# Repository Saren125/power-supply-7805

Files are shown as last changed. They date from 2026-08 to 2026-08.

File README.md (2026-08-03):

# power-supply-7805
## Особенности реализации (Топология платы)
* Среда проектирования: **Altium Designer**
* Количество слоев: **1 слой (Односторонняя печатная плата)**. Проект разработан с учетом минимизации стоимости серийного производства.
* **Тепловой менеджмент (Thermal Design):** Отвод тепла от микросхемы LM7805 реализован за счет создания максимально возможной площади медного полигона непосредственно на сигнальном слое вокруг вкладки (Tab) регулятора.
* **Трассировка:** Компоновка элементов выполнена оптимальным образом, что позволило полностью избежать пересечения проводников на одном слое и отказаться от использования проволочных перемычек (Jumpers).
* Фильтрующие керамические конденсаторы С1 и С3 (0.1 мкФ) размещены в максимальной физической близости к выводам питания микросхемы.

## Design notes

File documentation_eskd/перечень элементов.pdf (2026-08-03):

Изм. Лист | № докум. | Подп. | Дата
| Разраб. | | | Стабилизатор напряжения Перечень элементов | Лит. | Лист | Листов
Пров. | | | | | | | 1
Н.контр. Инв. № подл. Подп. и дата Взам. инв. № Инв. № дубл. Подп. и дата | Утв. Справ. № Перв. примен. | Конденсаторы
С1,C3 | Конденсатор керамический 0.1 МКФ 50В 10% 0603 GCM188R71H104KA57D Murata | 2
C2 | Конденсатор электролитический 10мкФ 50В 20% JRB1H100M02000500110000B JRB | 1

Микросхемы

DD1 | Стабилизатор напряжения TO-220 L7805CV Hottech | 1
| Резисторы
R1 | Резистор 1 кОм 0.1 Вт 0603 RC0603JR-071KL YAGEO | 1
| Приборы полупроводниковые
VD1 | Диод импульсный SMB ES2D On-Semiconductor | 1
VD2 | Диод Шоттки SMB SS220 YANGJIE | 1
VD3 | Светодиод красный 0603 GNL-0603EC G-nor Electronics | 1

Соединители

XT1,XT2 Вилка штыревая 2.54мм 1x2pin прямая PLS-2 (DS1021-1x2) Connfly electronic (Zhenqin) 2

Поз.
обозначение
Наименование | Кол. Примечание
Копировал | Формат A4

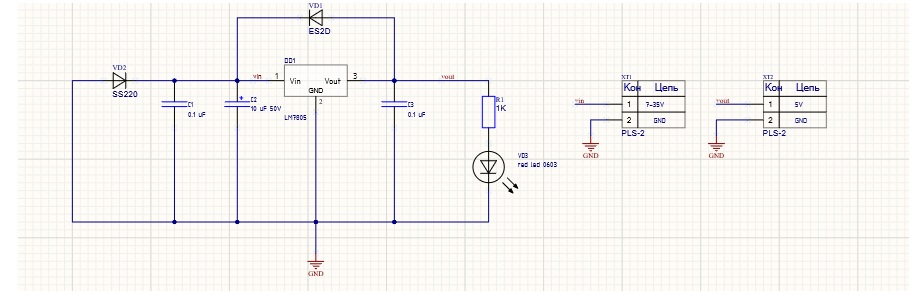
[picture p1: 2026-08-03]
screenshot.jpg

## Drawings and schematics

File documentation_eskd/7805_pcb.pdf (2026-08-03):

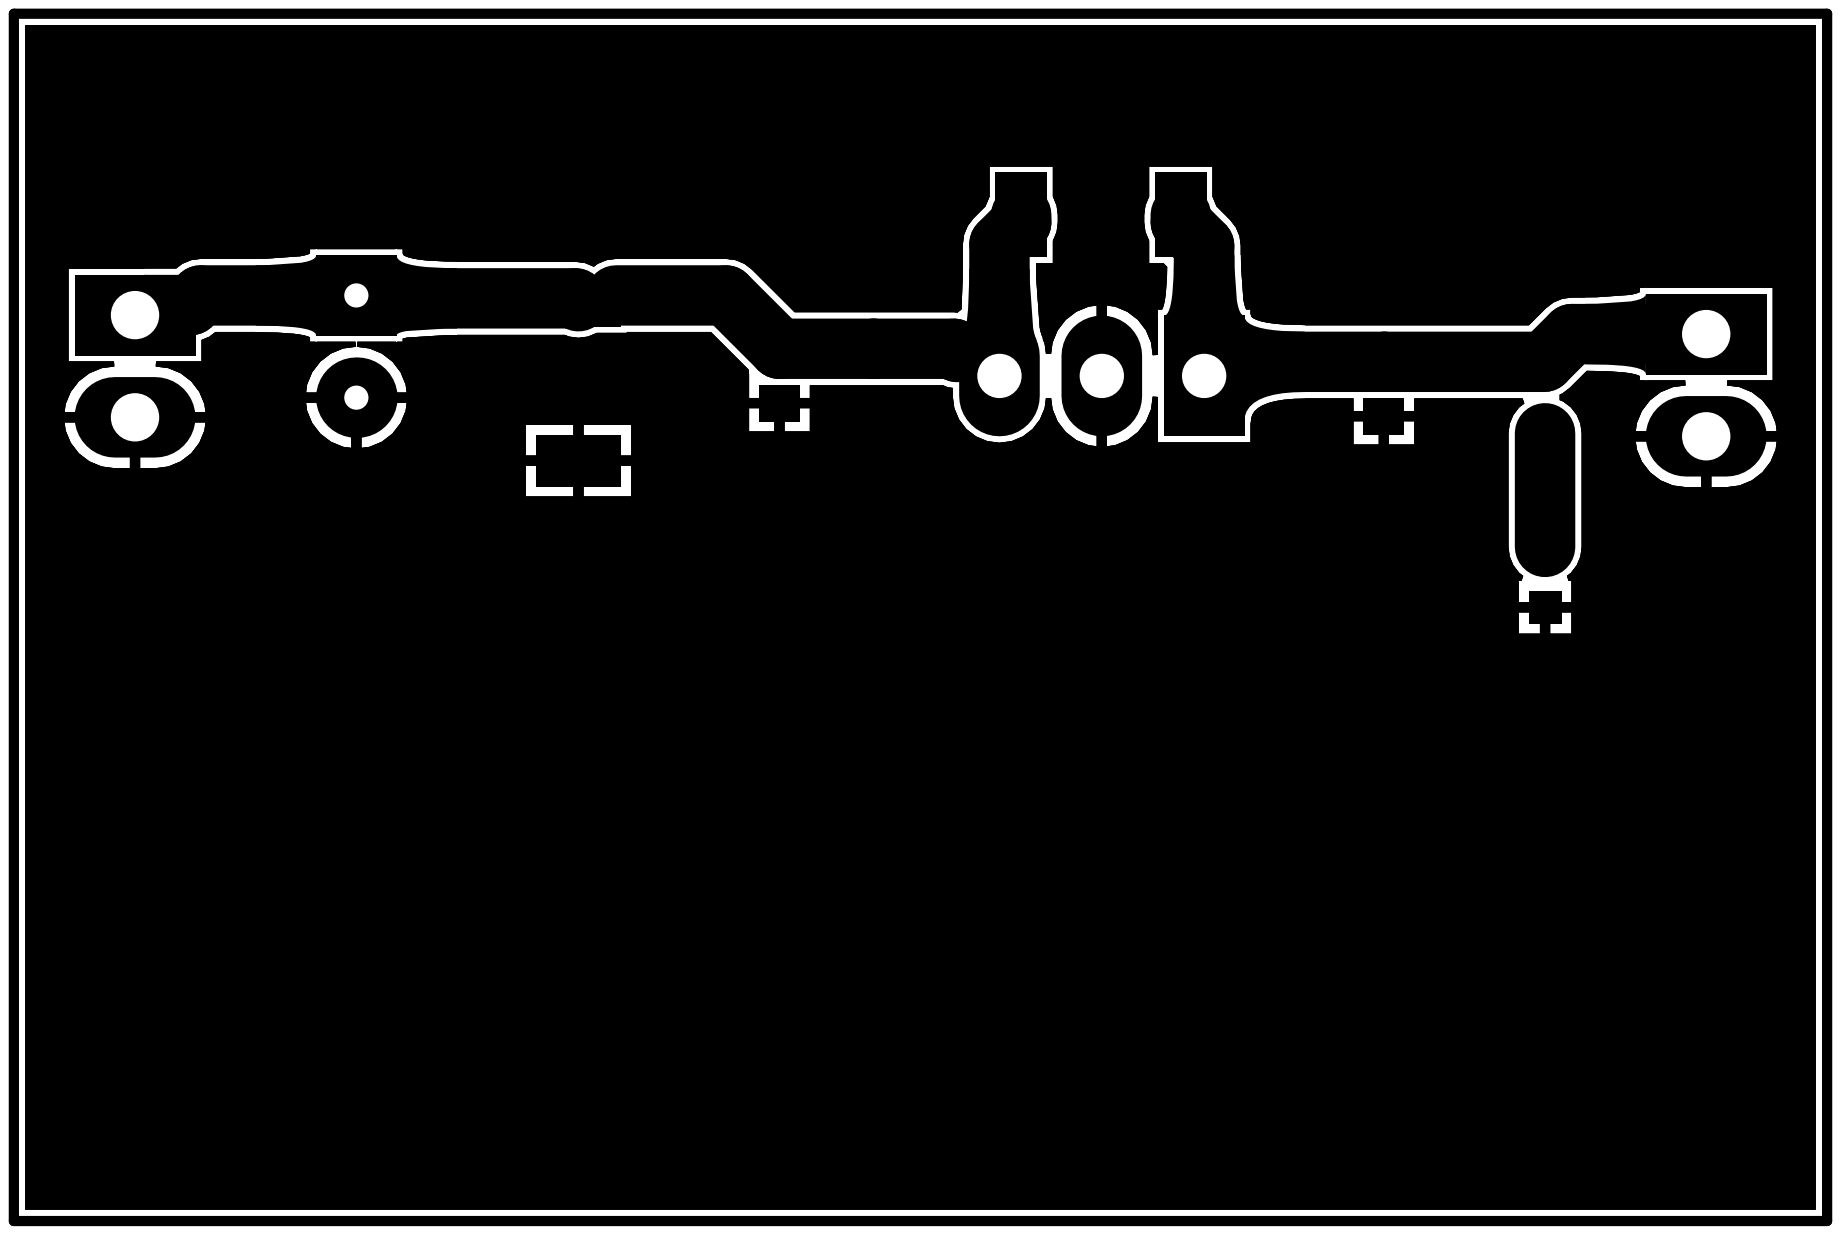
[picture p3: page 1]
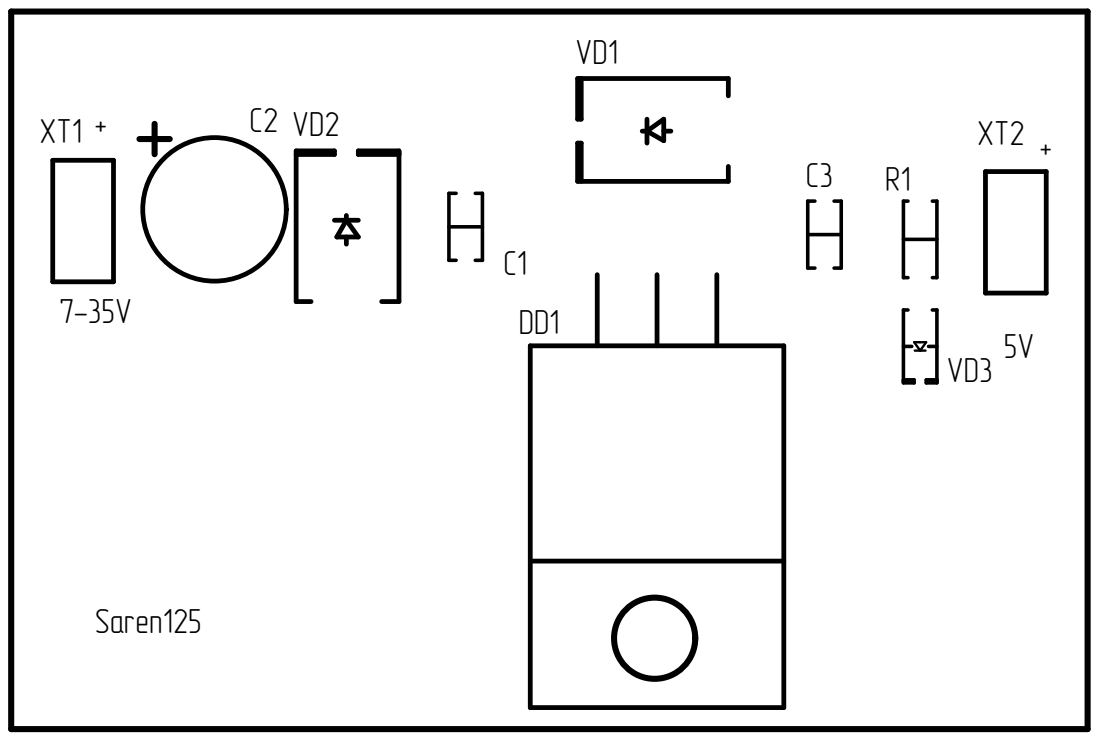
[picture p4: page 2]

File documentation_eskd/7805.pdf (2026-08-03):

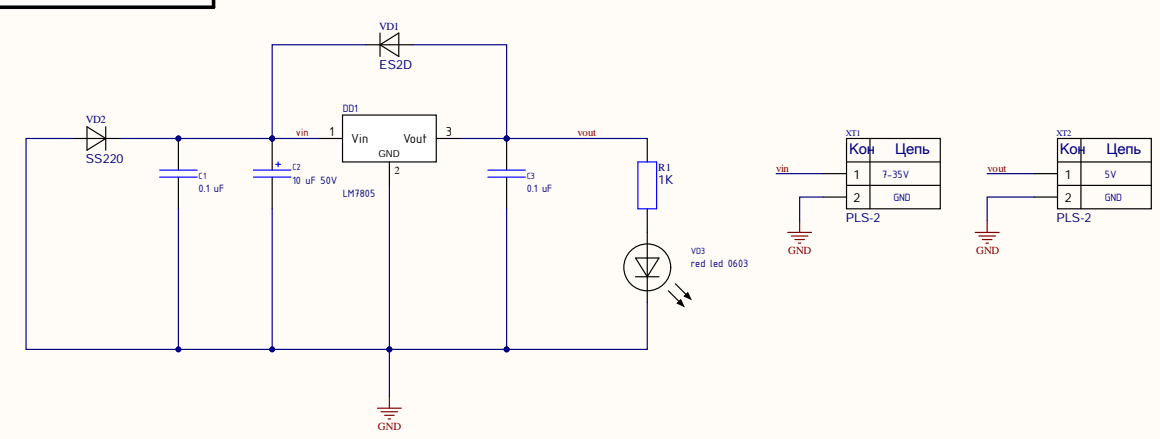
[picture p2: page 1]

Инв. № подл. Инв. № дубл. Подп. и дата Взам. инв. № Подп. и дата
